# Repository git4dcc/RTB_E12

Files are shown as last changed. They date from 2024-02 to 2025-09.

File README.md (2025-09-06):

# RTB_E12




This module implements a compact 12-channel WS2811 PCB designed to fit within a signal's socket. Connectivity is provided via an FFC cable to an adapter board (P15) mounted beneath the layout, which allows the signal to be easily detached—for example, during transportation. The E12 can be cascaded with other WS28xx compatible chips.

<details>
<summary>See also</summary>

- [RTB_E10](https://github.com/git4dcc/RTB_E10)
- [RTB_E13](https://github.com/git4dcc/RTB_E13)
- [RTB_E15](https://github.com/git4dcc/RTB_E15)

</details>

<details>
<summary>User Guides</summary>

- [User Guide - DE](https://rtb4dcc.de/ws2811_guide_de/)
- User Guide - EN

</details>

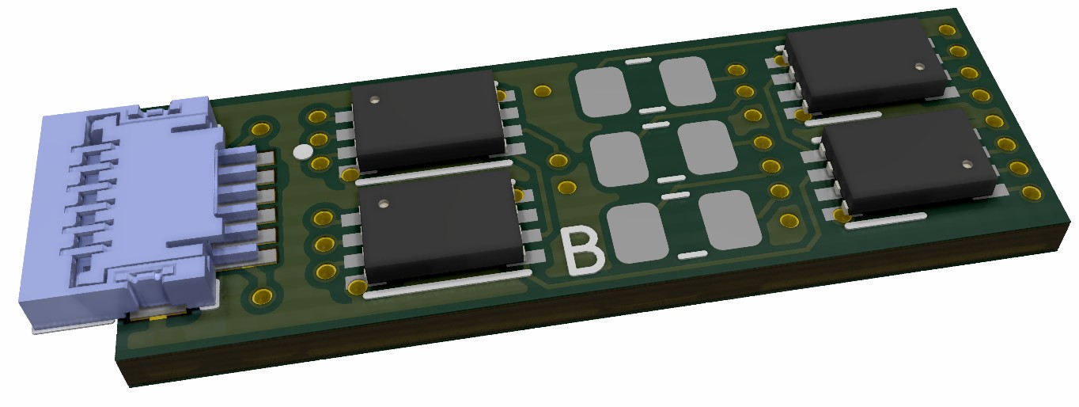
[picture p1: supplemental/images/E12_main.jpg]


The module has the following features,
- **Protocol**
  - WS2811 chip protocol
- **LED ports**
  - fixed 12 channel (4x WS2811 chips)
  - +5V common LED voltage (common anode)
  - 255 step PWM

# Hardware
The PCB layout uses SMD footprints with 0.5mm pitch and 0402 parts. Reflow soldering is mandatory.

The hardware does pull operation with 5V common.

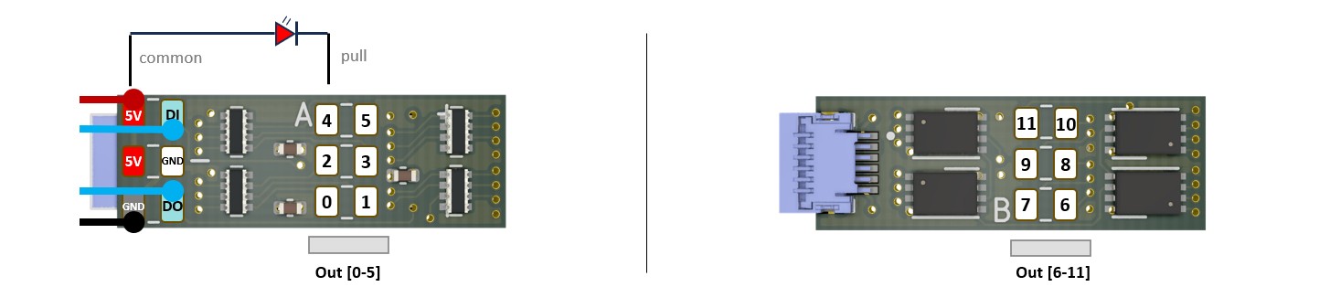
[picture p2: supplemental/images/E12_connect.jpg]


## PCB
- 4-layer PCB, FR4, 0.8mm, 18x6mm
- CPU: none (native WS2811 chips)
- BUS: WS2811
- LED: pull /w common anode
<br>

**Top**

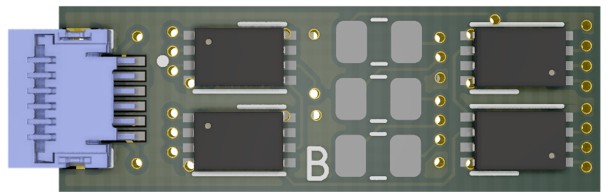
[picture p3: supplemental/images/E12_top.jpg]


**Bottom**

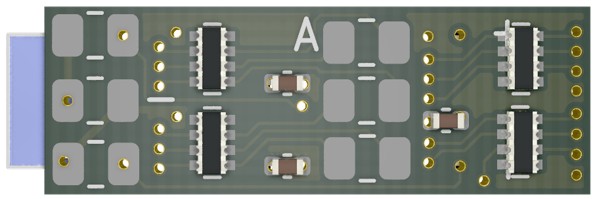
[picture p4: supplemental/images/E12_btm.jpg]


[Schematic](doc/E12_schematic.pdf) | [Layout](doc/E12_layout.pdf) | [Gerber](gerber)

## Firmware
This module does **not** have any firmware code (uses native WS2811 chips).

# Use Case
The E12 module is housed within the signal's socket and links to the adapter, located beneath the layout, through a flexible flat cable (FFC).

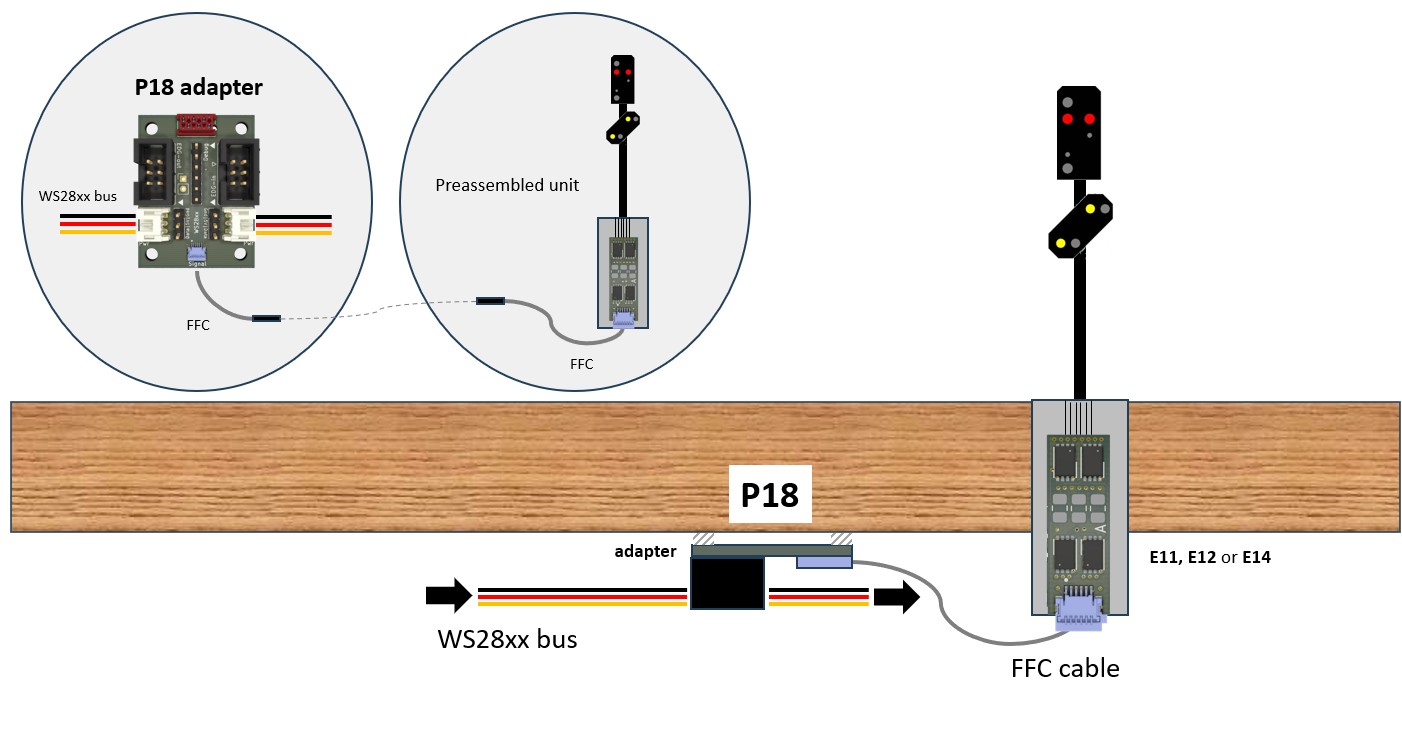
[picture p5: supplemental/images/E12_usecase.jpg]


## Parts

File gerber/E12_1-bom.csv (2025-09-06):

Value | Designator | Footprint | JLCPCB Part# | Description
100n | C1,C2,C3 | Capacitor_SMD:C_0402_1005Metric | C14663 | 100nF 50V X7R ñ10% 0603 Multilayer Ceramic Capacitors MLCC - SMD/SMT ROHS
FFC | J3 | AMPHENOL_59453-061110EDHLF | C3169668 | -55?~+85? 0.3mm 0.5mm 0.88mm 6P Bottom Contact Copper Alloy Gold Slide Lock Surface Mount, Right Angle SMD,P=0.5mm,Surface Mount?Right Angle FFC, FPC (Flat Flexible) Connector Assemblies ROHS
220 | RN1,RN2,RN3,RN4 | Resistor_SMD:R_Array_Concave_4x0402 | C25498 | 1/16W 220ê 4 8 ñ200ppm/? ñ5% 0402x4 Resistor Networks, Arrays ROHS
WS2811 | U1,U2,U3,U4 | Package_DFN_QFN:DFN-8-1EP_3x2mm_P0.5mm_EP1.36x1.46mm | C3034985 | -40?~+85? 16.5mA 20V 3 5V~24V 800kHz PWM VSON-8-EP(2x3) LED Drivers ROHS

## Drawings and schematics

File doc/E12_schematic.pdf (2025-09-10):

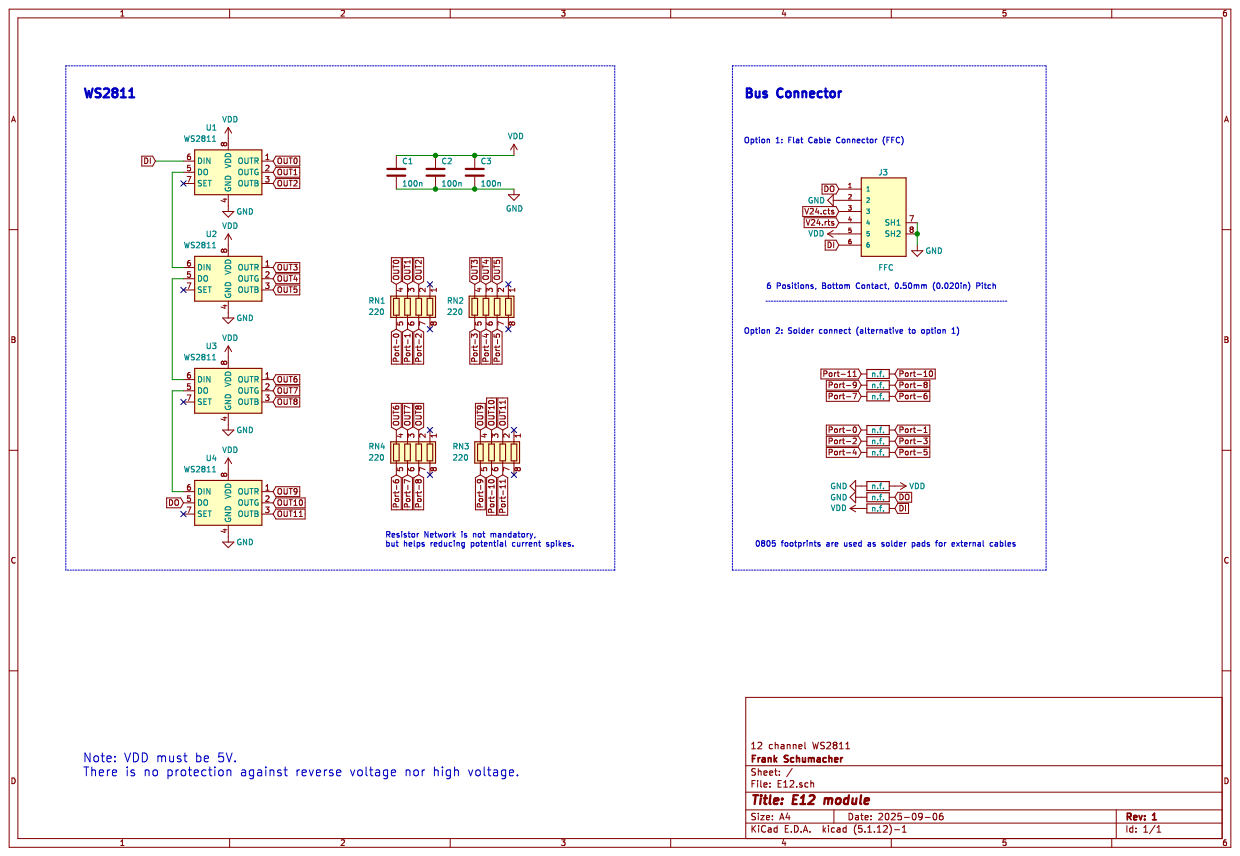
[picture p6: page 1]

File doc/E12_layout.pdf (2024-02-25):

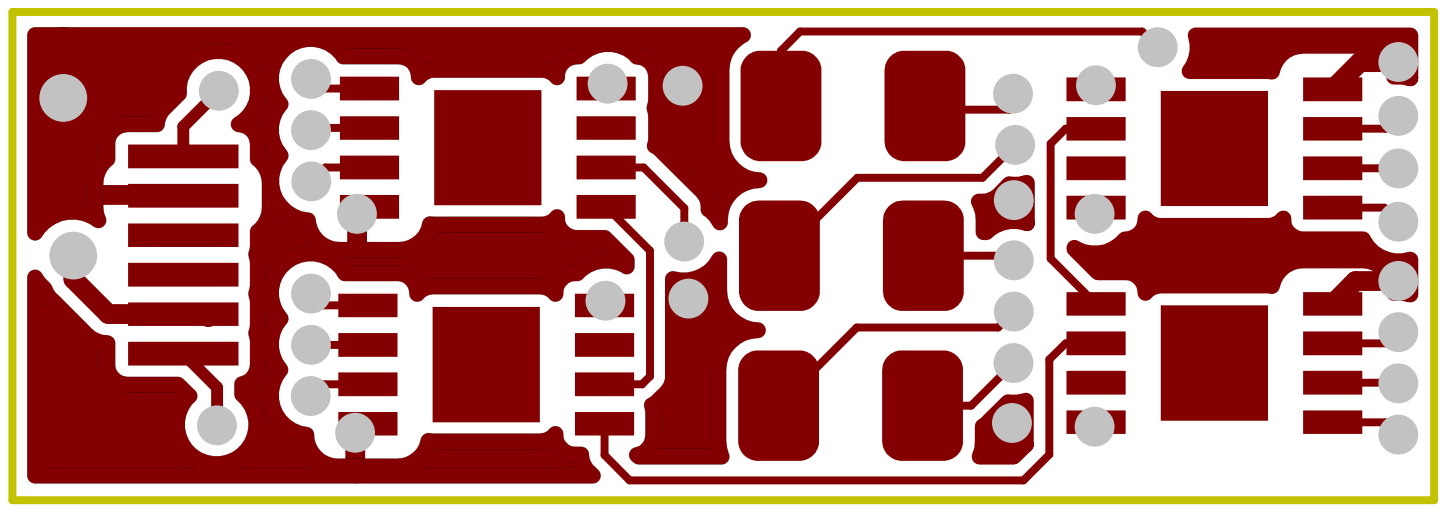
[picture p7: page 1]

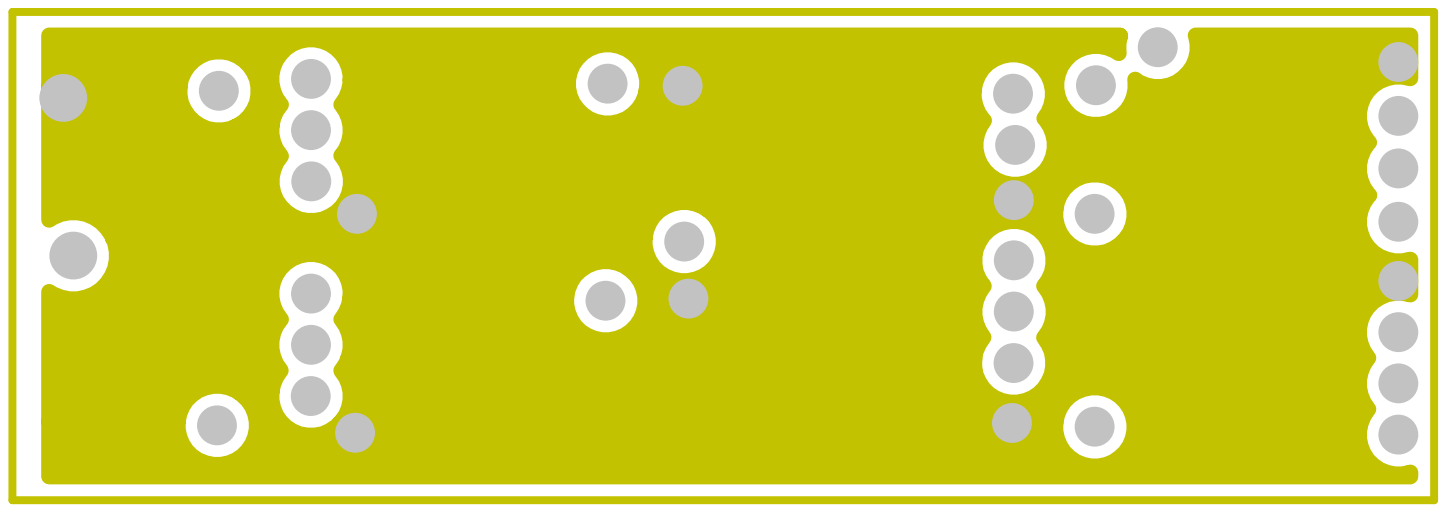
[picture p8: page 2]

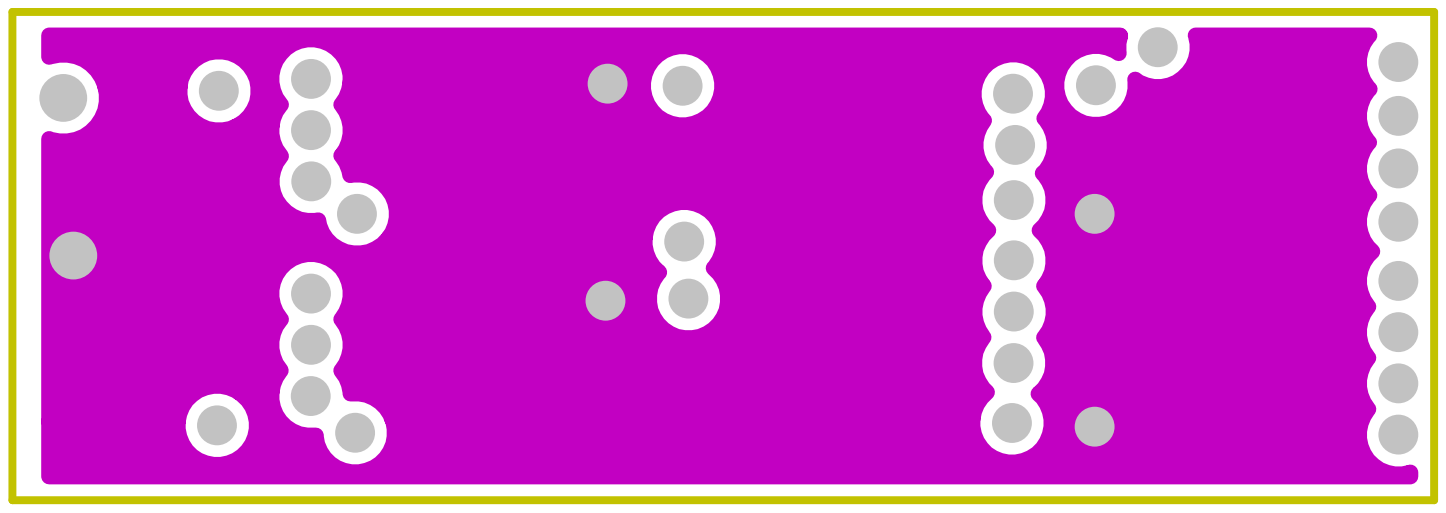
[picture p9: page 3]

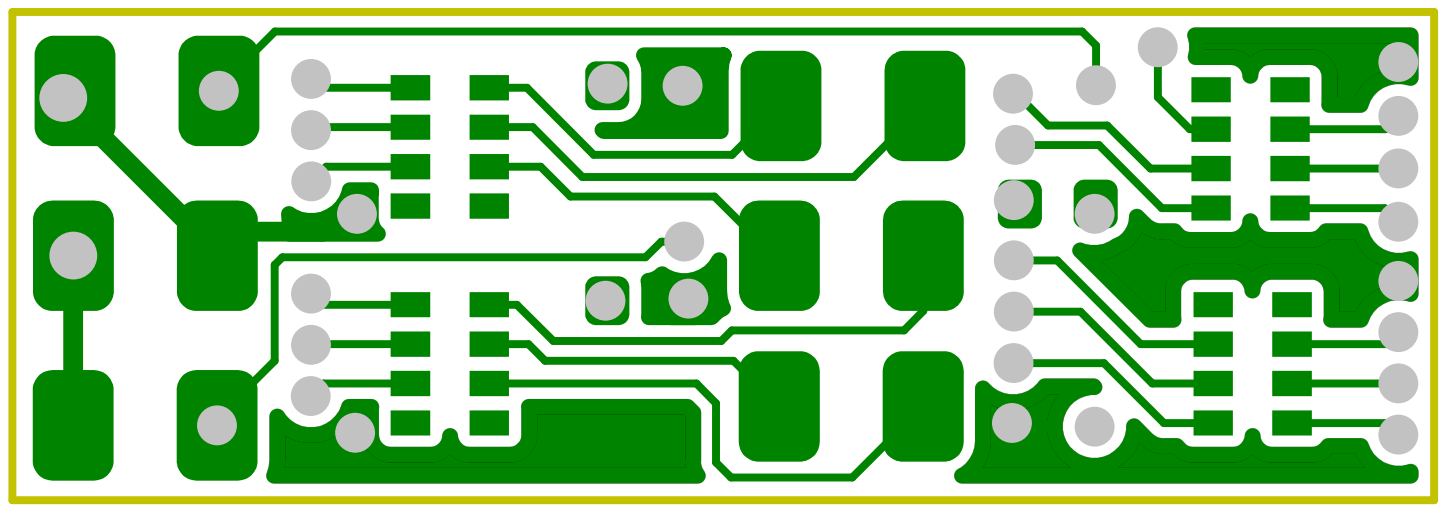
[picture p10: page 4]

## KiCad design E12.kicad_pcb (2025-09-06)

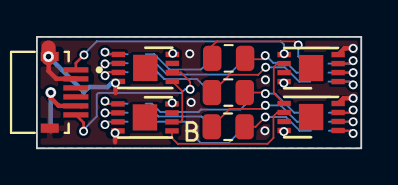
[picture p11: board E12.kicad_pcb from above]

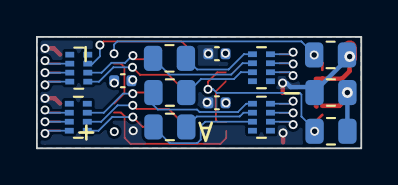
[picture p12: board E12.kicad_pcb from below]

Board: 4 copper layers, 18.0 x 6.2 mm, 21 parts (13 on the bottom side), 31 nets.

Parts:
C1, C2, C3: 100n; C_0402_1005Metric
J3: FFC; AMPHENOL_59453-061110EDHLF
R1, R2, R3, R4, R5, R6, R9, R11, R12: n.f.; R_0805_2012Metric
RN1, RN2, RN3, RN4: 220; R_Array_Concave_4x0402
U1, U2, U3, U4: WS2811; DFN-8-1EP_3x2mm_P0.5mm_EP1.36x1.46mm

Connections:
DI: J3.6, R12.1, U1.6
DO: J3.1, R11.1, U4.5
GND: C1.2, C2.2, C3.2, J3.2, J3.7, J3.8, R9.2, R11.2, U1.4, U2.4, U3.4, U4.4
unnamed: U1.5, U2.6
unnamed: U2.5, U3.6
unnamed: U3.5, U4.6
OUT0: RN1.4, U1.1
OUT1: RN1.3, U1.2
OUT2: RN1.2, U1.3
OUT3: RN2.4, U2.1
OUT4: RN2.3, U2.2
OUT5: RN2.2, U2.3
OUT6: RN4.4, U3.1
OUT7: RN4.3, U3.2
OUT8: RN4.2, U3.3
OUT9: RN3.4, U4.1
OUT10: RN3.3, U4.2
OUT11: RN3.2, U4.3
Port-0: R4.2, RN1.5
Port-1: R4.1, RN1.6
Port-2: R5.2, RN1.7
Port-3: R5.1, RN2.5
Port-4: R6.2, RN2.6
Port-5: R6.1, RN2.7
Port-6: R3.1, RN4.5
Port-7: R3.2, RN4.6
Port-8: R2.1, RN4.7
Port-9: R2.2, RN3.5
Port-10: R1.1, RN3.6
Port-11: R1.2, RN3.7
VDD: C1.1, C2.1, C3.1, J3.5, R9.1, R12.2, U1.8, U2.8, U3.8, U4.8

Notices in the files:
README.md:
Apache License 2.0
